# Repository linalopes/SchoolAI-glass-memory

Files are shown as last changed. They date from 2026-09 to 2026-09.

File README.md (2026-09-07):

# Glass Memory

A memory game played with the hands, on glass.

Five MDF hands sit on a transparent pane. Four of them hold a lamp. The fifth is Start. A small LED matrix waits, showing a single word. Place a hand on Start, watch the lamps light a sequence, then repeat that sequence by placing your hands on the other four. Each correct round adds one more step. A wrong direction, or a pause that lasts too long, ends the game and returns the panel to waiting.

The electronics stay visible: TRRS cables run across the glass, a custom controller board sits beside the display, and the lamps switch through a relay module. Nothing on the matrix ever names a direction. The sequence exists only as light, then as remembered gesture.

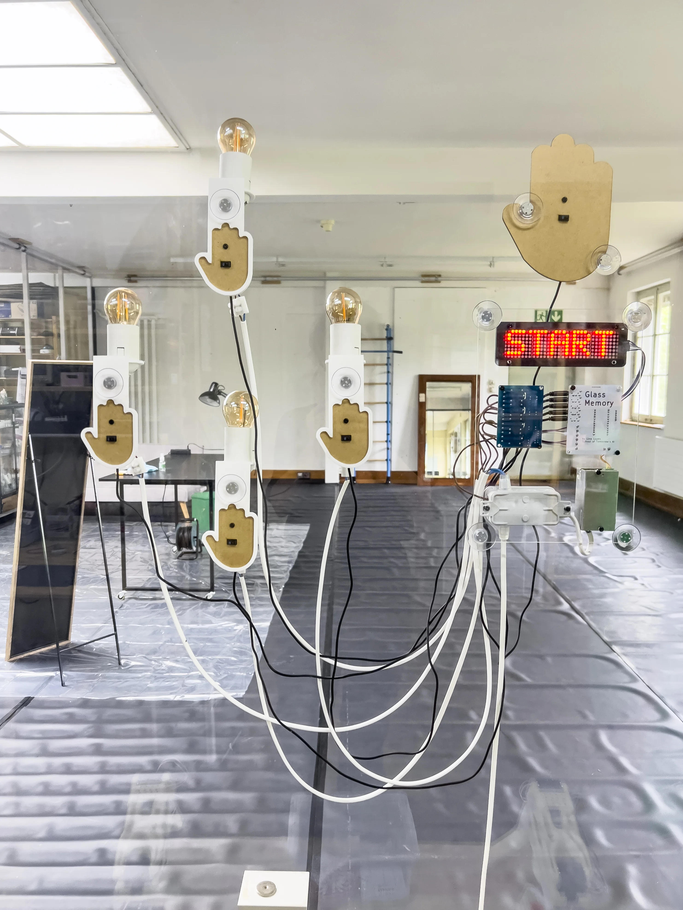
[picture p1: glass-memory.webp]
Glass Memory installation


https://github.com/user-attachments/assets/acf82029-6c34-4761-a3db-518c1ffbd78a

---

## How it works

The visitor sees a glass pane with five hand-shaped stations, a red 32×8 LED matrix, and four lamps.

1. The matrix shows **START**.
2. A hand over the Start station begins a game. Start does not light a lamp.
3. The matrix counts **3 · 2 · 1**, then shows the round length as a number.
4. The computer plays the sequence on the four direction lamps only. The display stays blank during playback and never reveals UP, DOWN, LEFT, or RIGHT as text.
5. The matrix shows **GO**. The visitor repeats the sequence on the four direction hands, one press at a time, releasing each hand before the next.
6. A complete correct round shows **OK**. The sequence grows by one random direction and the next round begins.
7. A wrong hand shows **WR**. Taking too long to press, or holding a press too long, shows **TO**. The matrix then shows the number of completed rounds and returns to **START**.

Repeated presses of the same direction count as separate events, as long as the hand is lifted in between. Only Start is accepted while idle; only the four directions are accepted during a turn.

`Start → countdown → watch lamps → GO → repeat → OK → longer sequence`

---

## System overview

```text
Five analog sensors (START, UP, DOWN, LEFT, RIGHT)
        ↓  TRRS cables + adapter boards
Arduino Pro Micro controller
        ↓
Game logic  (sequence, input events, EEPROM calibration)
   ↙                    ↘
MAX7219 matrix         4-channel relay module
(text / numbers)               ↓
                         Direction lamps
```

The controller reads five analog sensor channels, decides when a hand is present, and either plays a lamp sequence or checks the player’s reply. Calibration values live in EEPROM and are loaded at boot; the game firmware does not rewrite them.

---

## Hardware

The running firmware and the KiCad controller project both target a **SparkFun Pro Micro C** (ATmega32U4, [product 15795](https://www.sparkfun.com/products/15795)), socketed on the custom board.

The schematic title block still says “ESP32-S3 controller”. That comment is leftover. The symbol, footprint, pin map, and firmware all use the Pro Micro.

| Role | What is in this repo | Purpose |
| --- | --- | --- |
| Controller | SparkFun Pro Micro C on the [glass-memory](kicad%20files/glass-memory/) PCB | Runs calibration or game firmware |
| Sensor jacks | Five **PJ-320A** TRRS sockets (START, UP, DOWN, LEFT, RIGHT) | Detachable cable to each hand |
| Sensor adapters | Five [sensor-trrs-adapter-pj320a](kicad%20files/sensor-trrs-adapter-pj320a/) boards | PJ-320A jack to a 1×4 sensor header |
| Sensors | Five analog channels; 4-pin modules with **A0 / D0 / GND / VCC** on the adapter silkscreen | Detect a hand over each station |
| Display | External **MAX7219** 4-in-1 matrix (`FC16_HW`, 4 devices → 32×8) | Status text and numbers |
| Relays | External **4-channel relay module**, active LOW | Switch the four direction lamps |
| Power | 2-pin screw terminal **J8**, “5V Power Source” (pin 1 GND, pin 2 +5V) | 5 V rail shared with the Pro Micro `5V` pin |
| Mechanics | Laser-cut hands / board, 3D-printed hand support and matrix bezel | Physical stations on the glass |

The exact sensor part number is not named in the repository. Firmware comments treat the readings as optical (a slow “ambient optical drift” tracker). The adapter exposes both analog (**A0** / `AO`) and digital (**D0** / `DO`) pins; **only analog is used** by the firmware.

The installation photograph shows filament lamps at the four direction stations. This repository does not document lamp voltage or mains wiring. The relay stage switches those loads; any mains work must follow appropriate electrical safety practice.

### Controller pin map

Verified in both [glass-memory-game.ino](glass-memory-game/glass-memory-game.ino) and [glass-memory-calibration-eeprom.ino](glass-memory-calibration-eeprom/glass-memory-calibration-eeprom.ino), and matched on the Pro Micro footprint in the PCB.

| Function | Pin |
| --- | --- |
| START sensor | A10 |
| UP sensor | A9  |
| DOWN sensor | A8  |
| LEFT sensor | A0  |
| RIGHT sensor | A7  |
| Relay IN1 (UP) | D5  |
| Relay IN2 (DOWN)  | D4  |
| Relay IN3 (LEFT)  | D3  |
| Relay IN4 (RIGHT) | D2  |
| MAX7219 DIN | D15 |
| MAX7219 CS | D14 |
| MAX7219 CLK | D16 |

Relays are **active LOW** (`RELAY_ON = LOW`). START has no relay.

---

## Custom electronics

Two KiCad 10 projects ship with production gerbers. They are the current hardware, not a paper design only.

### Controller — [kicad files/glass-memory](kicad%20files/glass-memory/)

Silkscreen: *Glass Memory Controller 2026 - v1.0*. Outline **60 × 80 mm** with 2 mm corner radii (`Edge.Cuts` from 50.5,45 to 110.5,125), plus M3 holes.

The board is a hub:

- **U1** — socketed Pro Micro C
- **J1–J5** — PJ-320A TRRS jacks labeled START, UP, DOWN, LEFT, RIGHT
- **J6** — Phoenix MKDS 6-pin screw terminal, “RELAY 4 module”: `RELAY_IN4`, `RELAY_IN3`, `RELAY_IN2`, `RELAY_IN1`, `GND`, `+5V` (pins 1–6)
- **J7** — 5-pin header, “MAX7219 module”: `+5V`, `GND`, `DIN`, `CS`, `CLK` (pins 1–5)
- **J8** — Phoenix MKDS 2-pin screw terminal for 5 V in (pin 1 `GND`, pin 2 `+5V`). There is no on-board regulator; U1 `RAW` is unconnected.

Gerbers: [kicad files/glass-memory/production/](kicad%20files/glass-memory/production/).

### Sensor adapter — [kicad files/sensor-trrs-adapter-pj320a](kicad%20files/sensor-trrs-adapter-pj320a/)

Silkscreen: *TRRS PJ-320A 1×4 ADAPTER*. Schematic comment: *PJ-320A TRRS jack → 1×4 female header*.

One adapter sits at each hand. Board size in the gerber job is **24.6 × 15.1 mm**. The 1×4 header (J1) is:

| Pin | Net | Back silk |
| --- | ----- | --- |
| 1 | `AO`  | `A0` |
| 2 | `DO`  | `D0` |
| 3 | `GND` | `GND` |
| 4 | `3V3` | `VCC` |

Gerbers: [kicad files/sensor-trrs-adapter-pj320a/production/](kicad%20files/sensor-trrs-adapter-pj320a/production/).

---

## Sensor cabling

TRRS (PJ-320A, 3.5 mm 4-pole) is used so each hand can be a remote node: power, ground, and analog return travel in one detachable cable from the glass to the hub.

The table below follows the **PCB copper** on both boards (and the matching gerbers), using the custom [TRRS-PJ-320A](kicad%20files/glass-memory/TRRS-PJ-320A.pretty/TRRS-PJ-320A.kicad_mod) footprint labels.

| TRRS contact | Symbol pin | Controller PCB | Adapter PCB |
| --- | --- | --- | --- |
| Sleeve | S / pad 1  | `GND` | `GND` |
| Tip | T / pad 2  | not connected  | `DO` (digital out) |
| Ring 1 | R1 / pad 3 | `+5V` | net labeled `3V3` / silk `VCC` |
| Ring 2 | R2 / pad 4 | analog `*_A0`  | `AO` |

The controller uses **three** conductors. Tip is unused on the hub, so the sensor digital output is not read.

**Ambiguities to be aware of:**

1. The hub schematic *labels* next to the jacks appear to swap Sleeve and Ring 1 relative to the PCB (`+5V` on Sleeve, `GND` on Ring 1). The PCB, gerbers, and adapter all agree the other way: Sleeve = ground, Ring 1 = power. This README follows the copper.
2. The hub puts **+5 V** on Ring 1. The adapter net for that same contact is named **3V3**. Confirm the sensor module’s supply rating before applying power. TODO: document the intended sensor supply and module part number.

---

## Sensors

Five analog inputs, mapped as START / UP / DOWN / LEFT / RIGHT.

Each reading is an average of four ADC samples (first conversion after a channel change is discarded), then exponentially smoothed (`75%` previous + `25%` new). Presence is not a raw threshold. After calibration, a score of `0%` is the resting baseline and `100%` is the stored hand sample:

- press when score ≥ **50%** and that sensor beats the next by **10%**
- release when score < **30%**
- a press must stay stable **80 ms**; after release, the allowed sensors must stay neutral **120 ms** before the next press can arm

During a player turn the RAM baseline slowly follows ambient optical drift (every 100 ms, only while a sensor is well below the press threshold). EEPROM is not updated. The useful span is not allowed to collapse below a live delta of 20.

The game firmware latches one accepted sensor until *that same* sensor releases, so LEFT → LEFT is two events if the hand lifts in between.

---

## Calibration

Firmware: [glass-memory-calibration-eeprom/glass-memory-calibration-eeprom.ino](glass-memory-calibration-eeprom/glass-memory-calibration-eeprom.ino)

Optical rest levels shift with light and mounting. Calibration measures a clear-pane baseline and a hand sample per station, stores both in EEPROM, and is a **separate sketch** from the game.

Upload this sketch to the Pro Micro (Arduino IDE, board: SparkFun Pro Micro / ATmega32U4). Serial is 115200 baud. Calibration still runs if Serial is not open.

### Automatic flow

The matrix and Serial walk through the same sequence:

```text
CAL
CLEAR   → keep the complete sensor area clear → 3 · 2 · 1 → baseline
START   → prepare a hand over START → 3 · 2 · 1 → hand sample
UP      → same
DOWN
LEFT
RIGHT
DONE    → values written to EEPROM
TEST    → live sensor + relay check
```

Each measurement averages **120** analog samples with **4 ms** between samples. For every sensor the sketch stores:

- `baseline` — mean of the clear-pane capture
- `hand` — mean of that station’s hand capture
- `delta` — `hand − baseline`

Min/max during each capture are printed for noise diagnosis. The EEPROM record is:

```text
magic 0x474D ("GM") · version 1 · baseline[5] · hand[5] · checksum
```

The write is read back immediately (`EEPROM SAVE: OK` or `ERROR`). Values persist across power cycles. Resetting the board runs the whole calibration again.

### Live test

After SAVE, the sketch stays in TEST. An accepted sensor lights its relay (except START) and draws a marker on the matrix (center / top / bottom / left / right edge). Serial prints all five `filtered/score%` values twice a second, tagged `[ACTIVE]`, `[CAND]`, or `[--]`.

Send `P` on Serial to reprint the calibration table.

Then upload the game sketch. Do not recalibrate unless the mounting or lighting changed.

---

## Firmware

Current game firmware: [glass-memory-game/glass-memory-game.ino](glass-memory-game/glass-memory-game.ino) (**Game V4**).

It is not the calibration sketch. If EEPROM magic, version, checksum, or any sensor delta is invalid (`|delta| < 2`), the matrix shows **CAL** and the board waits there.

V4 responsibilities:

- load calibration; never write EEPROM
- continuous analog filter; slow RAM baseline tracking
- PRESS → LATCH → RELEASE → NEUTRAL → ARMED input machine
- idle wait on START only
- random direction sequence (UP/DOWN/LEFT/RIGHT), length 1…32
- lamp-only playback (`700 ms` on, `250 ms` gap)
- per-press timeout `10 s`, release timeout `5 s`
- player lamp feedback while the accepted hand is present (`PLAYER_LAMP_FEEDBACK`; set to `0` only for A/B diagnostics — computer playback always uses the lamps)
- serial debug at 115200 when `DEBUG_SERIAL` is 1

---

## Display

A four-module MAX7219 chain (`MD_MAX72XX::FC16_HW`, intensity 3). Firmware maps pixels with **X reversed** and **Y normal** (`physicalCol = 31 − logicalCol`) so the physical panel matches the intended left-to-right text.

| When | Matrix shows |
| --- | --- |
| Idle | `START` |
| Missing calibration | `CAL` (then halt) |
| New game | `3` `2` `1` |
| Before playback | round length as a number |
| Sequence playback | blank |
| Player turn | `GO` |
| Round correct | `OK` |
| Wrong hand | `WR`, then the score |
| Timeout | `TO`, then the score |

The 3D-printed [MAX7219 bezel](3D%20print%20files/glass_memory_max7219_beze.scad) is a rear-entry frame for a 32×8 assembly (~131 mm wide including inter-module gaps).

---

## Relays and lights

Four channels, active LOW, mapped as IN1–IN4 above. During computer playback each step turns on exactly one lamp. During the player turn the matching lamp stays on while that hand remains present (if player feedback is enabled). START never drives a relay. All relays are forced off between steps, on error, and in idle.

---

## Building the system

1. Fabricate the controller and one adapter per sensor (gerbers are under each project’s `production/` folder).
2. Seat the Pro Micro in the U1 socket.
3. Wire the MAX7219 module to J7 and the 4-channel relay module to J6.
4. At each hand, plug the 4-pin sensor into the adapter header and a TRRS cable from the adapter jack to the matching hub jack.
5. Supply 5 V on J8. Confirm sensor supply (see cabling note on +5 V vs `3V3`).
6. Upload **calibration**, clear the pane, then present a hand at each named station.
7. In TEST, confirm each direction lights the intended lamp and that Serial scores separate cleanly.
8. Upload **game** firmware. If the matrix shows `CAL`, calibration is missing or invalid — go back to step 6.
9. From idle, start a game and walk a short sequence before hanging the piece.

Laser-cut hands and board: [laser cut files](laser%20cut%20files/) (72 dpi SVG, plus `board.af`). 3D-printed hand support and matrix bezel: [3D print files](3D%20print%20files/). The hand OpenSCAD file is generated from the 72 dpi SVG contour (hand size ~60 × 80 mm, 3 mm MDF).

---

## Repository structure

```text
.
├── README.md
├── glass-memory.webp                          installation photograph
├── glass-memory.mp4                           installation video
├── glass-memory-game/                         game firmware V4
│   └── glass-memory-game.ino
├── glass-memory-calibration-eeprom/           EEPROM calibration + live TEST
│   └── glass-memory-calibration-eeprom.ino
├── kicad files/
│   ├── glass-memory/                          controller PCB + gerbers
│   └── sensor-trrs-adapter-pj320a/            per-sensor TRRS adapter + gerbers
├── laser cut files/                           hands, start hand, board (SVG / Affinity)
└── 3D print files/                            hand support + MAX7219 bezel
```

KiCad local history and zip backups exist under the hardware folders; they are snapshots, not the working design.

---

## Troubleshooting

Drawn from the diagnostic paths that actually exist in firmware.

| Symptom | What the firmware is telling you |
| --- | --- |
| Matrix stuck on `CAL` | EEPROM magic/version/checksum failed, or a stored delta is ~0. Run calibration and confirm `EEPROM SAVE: OK`. |
| Start does nothing, directions work (or the reverse) | Wrong TRRS jack, or the allowed-sensor mask: idle listens only to START; play listens only to the four directions. |
| One press counted twice, or LEFT cannot follow LEFT  | The hand never returned below the 30% release score for 120 ms. Check Serial scores in the calibration TEST. |
| Wrong lamp or two lamps | Winner margin is 10%. If two sensors both cross 50%, no winner is taken. Recalibrate with only one hand in place. |
| Resting scores creep up after a while | Expected: game tracks ambient drift in RAM only. If a real touch no longer reaches ~100%, recalibrate. |
| Display text mirrored | Firmware already reverses X for this panel. If it looks wrong, the module order or `FC16_HW` wiring does not match this build. |
| Relays on when they should be off | Modules are active LOW. Confirm the board is not treating IN as active HIGH. |
| `TO` during play | 10 s to make the next press, or 5 s to release. |
| Calibration deltas tiny | Baseline and hand samples were too similar. Repeat CLEAR with the pane empty, then place the hand fully over that station. |

Serial (both sketches, 115200) prints per-sensor scores when debug is on. Calibration TEST is the right place to watch `base` / `hand` / `delta` / `noise`.

---

## Software requirements

- Arduino IDE (or any environment that can flash a Pro Micro / ATmega32U4)
- Libraries referenced by `#include`: **MD_MAX72xx**, **SPI**, **EEPROM** (SPI and EEPROM are Arduino core libraries). No versions are pinned in this repo.
- **KiCad 10** (schematic `generator_version "10.0"`)
- **OpenSCAD**, if regenerating the 3D parts

---

## Glass Memory web app

This repository does not contain a web app, simulator, or networked companion. The installation runs entirely on the Pro Micro.

TODO: link a companion app here if it lives in another repo.

---

## About the project

Glass Memory is an embodied memory game: instructions arrive as lamps on glass, and the reply is a sequence of hands. The matrix is deliberately mute about direction. What you remember is a path of gestures, not a string of arrows.

The work sits in physical computing — analog optical sensing, a visible cable plant, calibration as a ritual of settling the pane to a room — rather than a hidden black-box kiosk.

PCB silkscreen: *heavily inspired by Nathan Rabinovitch*. No exhibition history is recorded in this repository.

---

## Credits

- **Lina Lopes** — School of Tomorrow's AI (controller and adapter silkscreen, 2026 v1.0)
- Inspired by **Nathan Rabinovitch**

TODO: license. No `LICENSE` file is present in this repository.

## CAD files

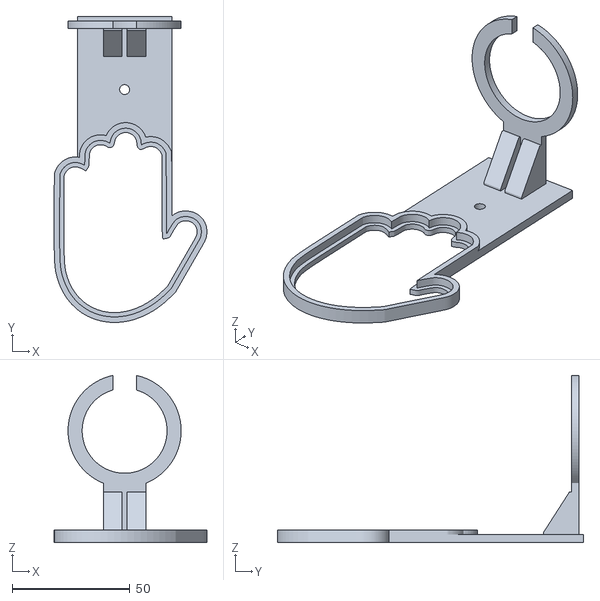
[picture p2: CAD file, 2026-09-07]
3D print files/glass_memory_hand_3Dprint.stl
64.8 x 129.8 x 70.9

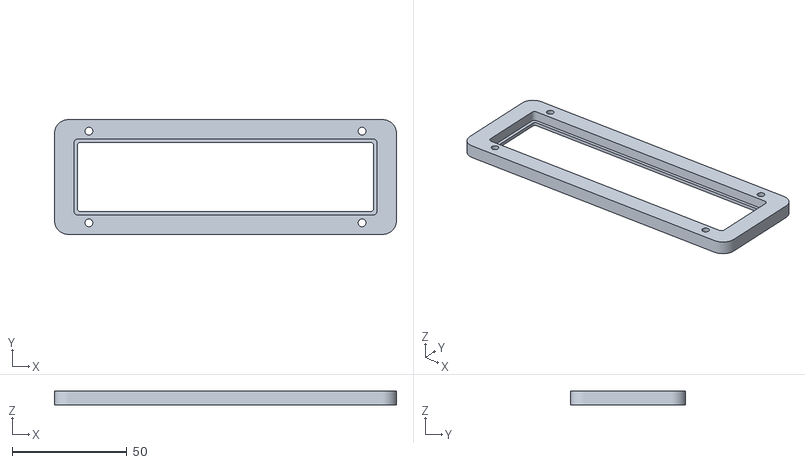
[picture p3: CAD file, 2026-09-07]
3D print files/glass_memory_max7219_bezel.stl
149.0 x 50.0 x 6.00

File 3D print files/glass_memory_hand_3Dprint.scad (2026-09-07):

// Glass Memory — hand sensor support v1
// Generated from the supplied 72 DPI SVG hand contour.
// Hand contour physical size: 59.989 x 80.002 mm
// All dimensions in mm.

$fn = 96;

// ---------- Main parameters ----------
hand_width = 59.9887;
hand_height = 80.0021;

mdf_thickness = 3.0;
mdf_clearance = 0.05  ;       // per side around MDF contour
front_bezel_thickness = 2.0;
channel_depth = 3.40;
outer_frame = 2.40;         // outside the MDF contour
front_overlap = 1.80;       // bezel overlaps MDF edge

tower_width = 40;
tower_height = 45;
tower_thickness = 3.4;
tower_overlap_into_hand = 0;
tower_bottom_y = hand_height + outer_frame;
tower_top_y = tower_bottom_y + tower_height;
// Negative = toward pinky (left in rear view). Right edge of the 40 mm tower
// aligns with the thumb-side outer hand contour (~17.5 mm after mirror + frame).
tower_x_offset = -2.5;

suction_hole_d = 4.2;
suction_hole_y = hand_height + 14;

shelf_y = tower_top_y - 5;   // shelf is as high as possible, 5 mm below top
shelf_thickness = 3.0;
rail_width = 18.0;

socket_inner_d = 36;
socket_radial_wall = 6.0;
socket_outer_d = socket_inner_d + 2*socket_radial_wall;
socket_gap = 10.0;          // lateral opening of the C-ring
socket_near_edge_offset = 20.0; // nearest edge of socket ring from rear face
socket_center_z = tower_thickness + socket_near_edge_offset + socket_outer_d/2;

// ---------- Exact hand contour ----------
hand_points = [
    [24.8773, 9.0321],
    [25.4107, 9.8499],
    [26.3283, 11.2570],
    [27.5462, 13.6811],
    [28.5143, 16.2909],
    [28.9072, 17.6181],
    [29.0130, 18.0419],
    [29.2271, 18.8989],
    [29.4792, 20.2679],
    [29.6721, 21.8559],
    [29.8142, 23.7969],
    [29.9092, 26.2229],
    [29.9094, 26.2340],
    [29.9674, 29.2669],
    [29.9944, 33.0610],
    [29.9944, 37.7370],
    [29.9835, 42.6180],
    [29.9835, 43.4290],
    [29.9354, 59.0021],
    [29.9354, 60.2790],
    [29.5623, 61.1971],
    [29.3385, 61.6831],
    [29.0704, 62.1570],
    [28.7614, 62.6131],
    [28.4164, 63.0481],
    [28.3703, 63.0981],
    [28.0404, 63.4561],
    [27.6374, 63.8331],
    [27.2125, 64.1750],
    [26.7696, 64.4771],
    [26.3135, 64.7330],
    [25.8494, 64.9409],
    [25.2205, 65.1579],
    [24.6064, 65.3129],
    [24.0015, 65.4050],
    [23.7285, 65.4180],
    [23.3986, 65.4341],
    [22.7916, 65.3989],
    [22.1764, 65.3000],
    [21.5436, 65.1349],
    [20.8895, 64.9049],
    [20.2064, 64.6070],
    [19.6325, 64.3152],
    [19.4904, 64.2429],
    [19.4724, 64.2689],
    [19.4534, 64.3639],
    [19.4335, 64.5210],
    [19.4126, 64.7351],
    [19.3925, 65.0010],
    [19.3724, 65.3119],
    [19.3536, 65.6640],
    [19.3385, 65.9934],
    [19.3385, 66.0501],
    [19.3224, 66.4649],
    [19.3084, 66.9041],
    [19.2986, 67.1941],
    [19.2785, 67.7410],
    [19.2414, 68.4530],
    [19.1904, 69.0600],
    [19.1665, 69.2420],
    [19.1224, 69.5809],
    [19.0324, 70.0349],
    [18.9144, 70.4429],
    [18.7654, 70.8221],
    [18.5805, 71.1930],
    [18.5226, 71.2901],
    [18.3540, 71.5740],
    [18.0820, 71.9849],
    [17.8510, 72.3011],
    [17.6002, 72.6030],
    [17.3301, 72.8911],
    [17.0422, 73.1631],
    [16.7382, 73.4171],
    [16.4199, 73.6550],
    [16.0879, 73.8719],
    [15.7460, 74.0701],
    [15.5391, 74.1722],
    [15.3920, 74.2450],
    [15.0301, 74.3990],
    [14.4591, 74.5770],
    [13.8352, 74.6972],
    [13.1769, 74.7580],
    [12.5030, 74.7652],
    [11.8299, 74.7181],
    [11.4431, 74.6599],
    [11.1780, 74.6199],
    [10.5639, 74.4720],
    [10.0059, 74.2770],
    [9.5230, 74.0370],
    [9.3950, 73.9442],
    [9.1320, 73.7531],
    [9.0290, 73.6640],
    [8.9420, 73.6021],
    [8.9010, 73.5851],
    [8.8690, 73.5719],
    [8.8081, 73.5769],
    [8.7549, 73.6211],
    [8.7070, 73.7071],
    [8.6610, 73.8399],
    [8.6139, 74.0230],
    [8.5639, 74.2611],
    [8.5081, 74.5569],
    [8.4679, 74.7194],
    [8.3065, 75.3711],
    [8.2964, 75.3861],
    [8.0141, 76.1349],
    [7.6421, 76.8451],
    [7.3431, 77.2769],
    [7.1920, 77.4951],
    [6.6679, 78.0820],
    [6.0750, 78.6011],
    [5.4180, 79.0469],
    [4.6999, 79.4150],
    [3.9271, 79.7031],
    [3.2471, 79.8682],
    [3.1040, 79.9031],
    [2.0070, 80.0021],
    [0.9299, 79.9031],
    [-0.1089, 79.6240],
    [-0.4221, 79.4822],
    [-0.8489, 79.2885],
    [-1.0860, 79.1811],
    [-1.9821, 78.5910],
    [-2.7740, 77.8711],
    [-3.4410, 77.0350],
    [-3.9609, 76.1032],
    [-4.2110, 75.3861],
    [-4.3139, 75.0901],
    [-4.4779, 74.0130],
    [-4.4901, 73.8291],
    [-4.5020, 73.6542],
    [-4.5171, 73.4909],
    [-4.5319, 73.3420],
    [-4.5324, 73.3380],
    [-4.5491, 73.2091],
    [-4.5650, 73.0962],
    [-4.5819, 73.0030],
    [-4.5981, 72.9340],
    [-4.6139, 72.8911],
    [-4.6290, 72.8750],
    [-4.6499, 72.8789],
    [-4.6830, 72.8911],
    [-4.7269, 72.9110],
    [-4.7801, 72.9361],
    [-4.8431, 72.9671],
    [-4.9121, 73.0041],
    [-4.9449, 73.0221],
    [-4.9870, 73.0451],
    [-5.0669, 73.0901],
    [-5.1500, 73.1380],
    [-5.2349, 73.1890],
    [-5.2669, 73.2054],
    [-5.7773, 73.4711],
    [-6.3663, 73.6970],
    [-6.9912, 73.8669],
    [-7.6421, 73.9820],
    [-8.3062, 74.0399],
    [-8.9732, 74.0410],
    [-9.0412, 74.0349],
    [-9.6312, 73.9831],
    [-10.2691, 73.8680],
    [-10.8753, 73.6941],
    [-11.4391, 73.4610],
    [-11.8183, 73.2560],
    [-12.1942, 73.0160],
    [-12.5633, 72.7440],
    [-12.9203, 72.4450],
    [-13.2621, 72.1209],
    [-13.5852, 71.7780],
    [-13.8852, 71.4190],
    [-13.9802, 71.2901],
    [-14.1575, 71.0491],
    [-14.3993, 70.6710],
    [-14.6054, 70.2889],
    [-15.0943, 69.2891],
    [-15.0943, 67.1941],
    [-15.1163, 59.0021],
    [-15.1343, 52.2301],
    [-15.1444, 49.4731],
    [-15.1565, 46.8529],
    [-15.1713, 44.4071],
    [-15.1854, 42.6180],
    [-15.1854, 42.1719],
    [-15.2044, 40.1820],
    [-15.2245, 38.5220],
    [-15.2251, 38.4741],
    [-15.2460, 37.0829],
    [-15.2589, 36.4741],
    [-15.2690, 36.0450],
    [-15.2909, 35.3949],
    [-15.3140, 35.1711],
    [-15.3391, 35.1771],
    [-15.3671, 35.1930],
    [-15.3989, 35.2190],
    [-15.4330, 35.2541],
    [-15.4431, 35.2660],
    [-15.4679, 35.2970],
    [-15.5050, 35.3470],
    [-15.5410, 35.4031],
    [-15.5769, 35.4640],
    [-15.6000, 35.5063],
    [-15.6129, 35.5301],
    [-15.6460, 35.5992],
    [-15.8640, 36.0392],
    [-16.1011, 36.4741],
    [-16.1551, 36.5731],
    [-16.5019, 37.1710],
    [-16.8869, 37.8060],
    [-17.2261, 38.3455],
    [-17.2909, 38.4490],
    [-17.3391, 38.5220],
    [-17.6973, 39.0721],
    [-18.0844, 39.6460],
    [-18.4384, 40.1431],
    [-18.7374, 40.5350],
    [-18.7684, 40.5701],
    [-18.9655, 40.7921],
    [-19.3033, 41.1009],
    [-19.6484, 41.3761],
    [-20.0045, 41.6190],
    [-20.3715, 41.8301],
    [-20.7514, 42.0100],
    [-21.1475, 42.1611],
    [-21.3224, 42.2124],
    [-21.5605, 42.2820],
    [-21.9934, 42.3751],
    [-22.4463, 42.4410],
    [-22.9234, 42.4791],
    [-23.5385, 42.4910],
    [-24.1354, 42.4601],
    [-24.7135, 42.3881],
    [-25.2684, 42.2751],
    [-25.4184, 42.2317],
    [-25.8015, 42.1211],
    [-26.3095, 41.9272],
    [-26.7913, 41.6930],
    [-27.2445, 41.4210],
    [-27.6695, 41.1102],
    [-28.0624, 40.7612],
    [-28.4764, 40.3302],
    [-28.8365, 39.8931],
    [-29.1445, 39.4441],
    [-29.4025, 38.9811],
    [-29.6025, 38.5220],
    [-29.6123, 38.4990],
    [-29.7753, 37.9950],
    [-29.8914, 37.4642],
    [-29.9645, 36.9020],
    [-29.9944, 36.3061],
    [-29.9835, 35.6711],
    [-29.9573, 35.1951],
    [-29.9174, 34.7789],
    [-29.8515, 34.4260],
    [-29.8414, 34.3831],
    [-29.7134, 33.9590],
    [-29.5115, 33.4661],
    [-29.2154, 32.8591],
    [-28.8053, 32.0940],
    [-28.2613, 31.1280],
    [-27.8031, 30.3300],
    [-27.5655, 29.9159],
    [-26.6955, 28.4149],
    [-26.2875, 27.7119],
    [-26.0978, 27.3841],
    [-25.8094, 26.8851],
    [-25.4324, 26.2340],
    [-25.2705, 25.9540],
    [-24.6855, 24.9409],
    [-24.0645, 23.8670],
    [-23.4213, 22.7531],
    [-23.1972, 22.3639],
    [-22.7683, 21.6202],
    [-22.1164, 20.4891],
    [-21.4785, 19.3831],
    [-20.8673, 18.3211],
    [-20.7067, 18.0419],
    [-17.2655, 12.0650],
    [-17.2245, 12.0240],
    [-15.4253, 10.2259],
    [-15.0205, 9.8499],
    [-13.1584, 8.1209],
    [-10.8084, 6.2460],
    [-8.3864, 4.6069],
    [-5.9054, 3.2089],
    [-3.3783, 2.0550],
    [-0.8404, 1.1610],
    [-0.8174, 1.1509],
    [1.7657, 0.5051],
    [4.3557, 0.1201],
    [6.9425, 0.0000],
    [7.3516, 0.0241],
    [9.5135, 0.1519],
    [12.1567, 0.6077],
    [14.6776, 1.3568],
    [15.5436, 1.7312],
    [15.8127, 1.8476],
    [17.0605, 2.3868],
    [19.2885, 3.6819],
    [21.3467, 5.2290],
    [23.2176, 7.0167],
    [24.8876, 9.0300]
];

module hand2d() {
    mirror([1,0,0]) polygon(points=hand_points);
}

module front_bezel_2d() {
    difference() {
        offset(r=outer_frame) hand2d();
        offset(delta=-front_overlap) hand2d();
    }
}
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

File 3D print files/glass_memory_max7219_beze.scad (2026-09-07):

/*
  Glass Memory — MAX7219 32x8 front bezel / mounting frame — v2

  Adjusted for 4-in-1 matrices with ~1 mm gap between the four 8x8 modules.
  Estimated active assembly width: 4 x 32 mm + 3 x 1 mm = 131 mm.

  Design:
  - MAX7219 enters from the rear
  - thin front retaining lip
  - rear remains open
  - rounded outer corners
  - four M3 clearance holes in the bezel
*/

$fn = 64;

// ---------- User parameters ----------
module_w = 131.0;          // 128 mm + ~3 mm total inter-module gaps
module_h = 32.0;
module_clearance = 1.0;    // total clearance: 0.5 mm per side

// 1.5 mm retaining lip around the module face
opening_w = 129.0;
opening_h = 30.0;

// Keep the same frame margins as v1, adding 3 mm to overall width
outer_w = 149.0;
outer_h = 50.0;
outer_r = 6.0;

// Depth geometry
bezel_depth = 6.0;
front_lip_thickness = 1.5;

// M3 clearance holes
screw_d = 3.4;
screw_x_inset = 15.0;
screw_y_inset = 5.0;

// ---------- Derived values ----------
pocket_w = module_w + module_clearance; // 132 mm
pocket_h = module_h + module_clearance; // 33 mm

// ---------- Helpers ----------
module rounded_rect_2d(w, h, r) {
  hull() {
    translate([ r,  r]) circle(r=r);
    translate([w-r,  r]) circle(r=r);
    translate([ r, h-r]) circle(r=r);
    translate([w-r,h-r]) circle(r=r);
  }
}

module centered_rounded_rect_prism(w, h, d, r) {
  translate([-w/2, -h/2, 0])
    linear_extrude(height=d)
      rounded_rect_2d(w, h, r);
}

module screw_hole(x, y) {
  translate([x, y, -0.5])
    cylinder(h=bezel_depth + 1.0, d=screw_d);
}

// ---------- Final model ----------
difference() {
  centered_rounded_rect_prism(outer_w, outer_h, bezel_depth, outer_r);

  // Front viewing opening
  translate([0, 0, -0.5])
    centered_rounded_rect_prism(opening_w, opening_h, bezel_depth + 1.0, 1.2);

  // Rear pocket
  translate([0, 0, front_lip_thickness])
    centered_rounded_rect_prism(
      pocket_w,
      pocket_h,
      bezel_depth - front_lip_thickness + 0.5,
      1.5
    );

  // Four M3 clearance holes
  for (sx = [-1, 1])
    for (sy = [-1, 1])
      screw_hole(
        sx * (outer_w/2 - screw_x_inset),
        sy * (outer_h/2 - screw_y_inset)
      );
}

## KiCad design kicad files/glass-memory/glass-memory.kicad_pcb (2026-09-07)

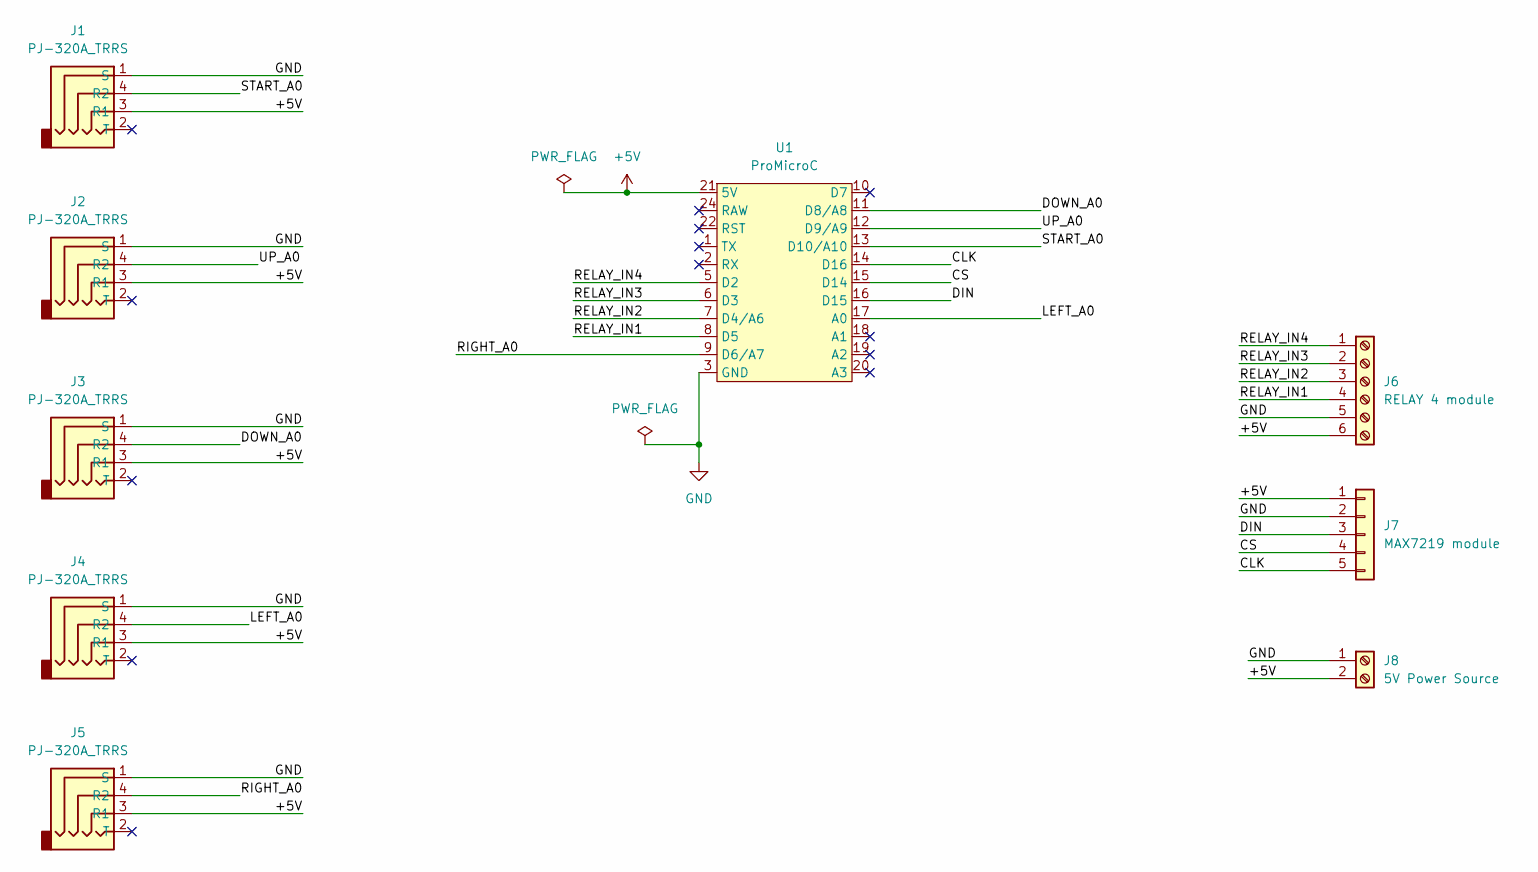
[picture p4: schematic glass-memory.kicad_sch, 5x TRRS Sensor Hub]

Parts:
J1, J2, J3, J4, J5: PJ-320A_TRRS; TRRS-PJ-320A
J6: RELAY 4 module; TerminalBlock_Phoenix_MKDS-1,5-6-5.08_1x06_P5.08mm_Horizont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
J7: MAX7219 module; PinHeader_1x05_P2.54mm_Vertical
J8: 5V Power Source; TerminalBlock_Phoenix_MKDS-1,5-2-5.08_1x02_P5.08mm_Horizont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
U1: ProMicroC; ProMicroC-socketed

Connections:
+5V: J1.3 (R1), J2.3 (R1), J3.3 (R1), J4.3 (R1), J5.3 (R1), J6.6, J7.1, J8.2, U1.21 (5V)
/CLK: J7.5, U1.14 (D16)
/CS: J7.4, U1.15 (D14)
/DIN: J7.3, U1.16 (D15)
/DOWN_A0: J3.4 (R2), U1.11 (D8/A8)
/LEFT_A0: J4.4 (R2), U1.17 (A0)
/RELAY_IN1: J6.4, U1.8 (D5)
/RELAY_IN2: J6.3, U1.7 (D4/A6)
/RELAY_IN3: J6.2, U1.6 (D3)
/RELAY_IN4: J6.1, U1.5 (D2)
/RIGHT_A0: J5.4 (R2), U1.9 (D6/A7)
/START_A0: J1.4 (R2), U1.13 (D10/A10)
/UP_A0: J2.4 (R2), U1.12 (D9/A9)
GND: J1.1 (S), J2.1 (S), J3.1 (S), J4.1 (S), J5.1 (S), J6.5, J7.2, J8.1, U1.3 (GND), U1.4 (GND), U1.23 (GND)

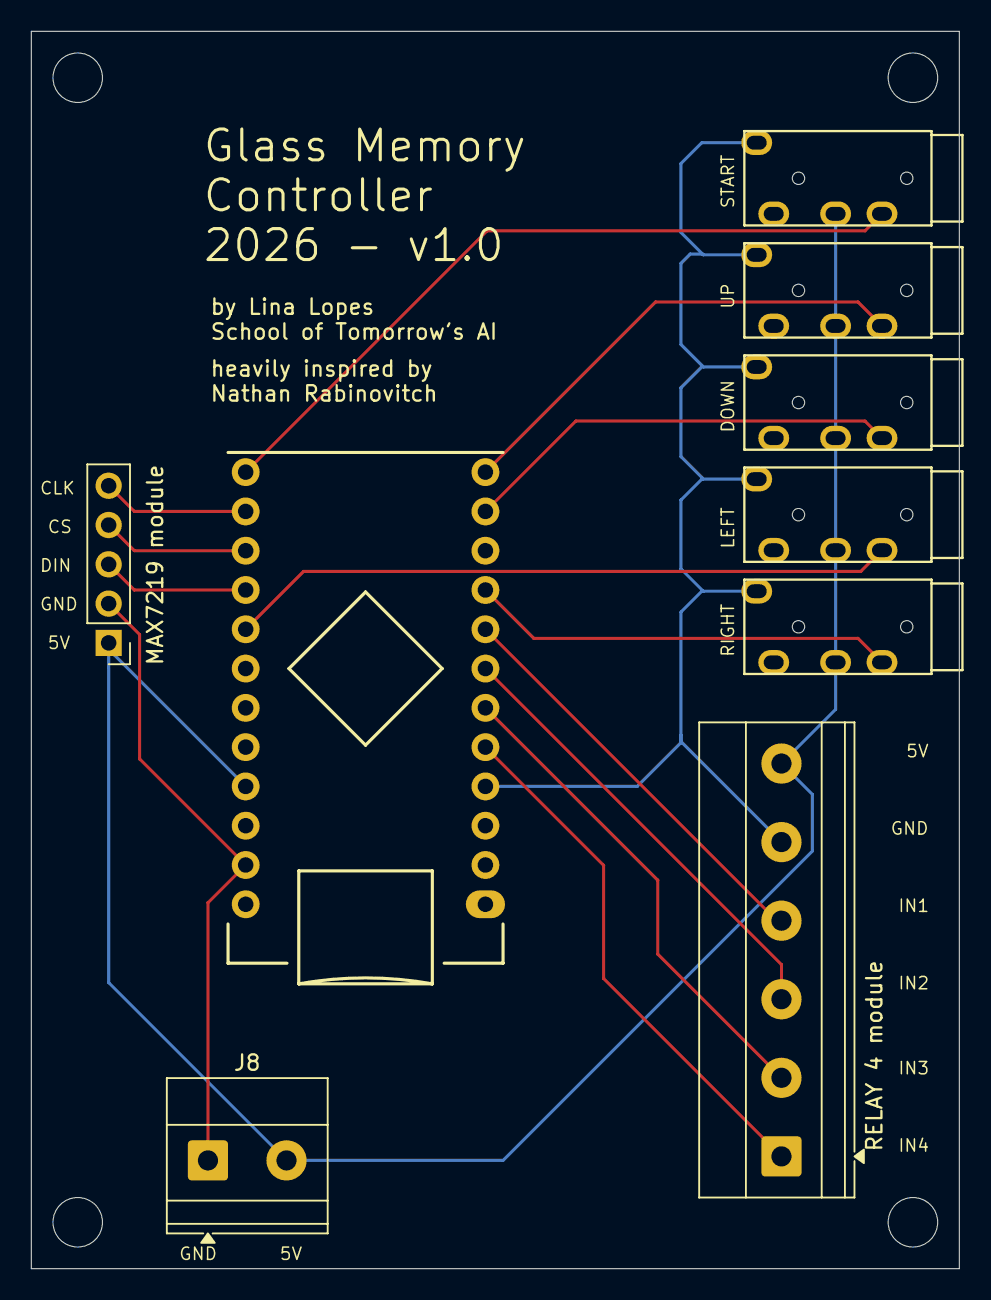
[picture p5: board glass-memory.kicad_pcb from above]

Board: 2 copper layers, 60.0 x 80.0 mm, 9 parts (0 on the bottom side), 14 nets.

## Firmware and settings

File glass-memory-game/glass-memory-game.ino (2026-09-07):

#include <MD_MAX72xx.h>
#include <SPI.h>
#include <EEPROM.h>

// ============================================================
// GLASS MEMORY - GAME V4
// Board: Arduino Pro Micro / ATmega32U4
//
// V4 is rebuilt around the validated PRESS -> LATCH ->
// RELEASE -> NEUTRAL -> ARMED input detector.
//
// Main changes from V1/V2/V3:
// - One sensor press is latched until THAT SAME sensor releases.
// - Repeated directions such as LEFT -> LEFT are independent events.
// - START only participates while idle.
// - Only UP/DOWN/LEFT/RIGHT participate during the player turn.
// - The analog filter stays continuous inside a player round.
// - The resting baseline slowly follows ambient optical drift in RAM.
// - EEPROM calibration is never rewritten by the game.
// - Player input timeout is per expected press.
// - Relay/lamp feedback stays on while the accepted hand is present.
//
// Display:
// - X axis reversed
// - Y axis normal
// - Display never reveals a direction.
//
// Relays:
// - ACTIVE LOW
// - IN1 = UP    -> D5
// - IN2 = DOWN  -> D4
// - IN3 = LEFT  -> D3
// - IN4 = RIGHT -> D2
// ============================================================


// ------------------------------------------------------------
// DEBUG
// ------------------------------------------------------------

#define DEBUG_SERIAL 1

#if DEBUG_SERIAL
  #define DBG_BEGIN(baud) Serial.begin(baud)
  #define DBG_PRINT(x) Serial.print(x)
  #define DBG_PRINTLN(x) Serial.println(x)
#else
  #define DBG_BEGIN(baud)
  #define DBG_PRINT(x)
  #define DBG_PRINTLN(x)
#endif


// ------------------------------------------------------------
// PLAYER LAMP FEEDBACK
//
// Set to 0 only for A/B diagnostics.
// Computer sequence playback always uses the lamps.
// ------------------------------------------------------------

#define PLAYER_LAMP_FEEDBACK 1


// ------------------------------------------------------------
// MAX7219
// ------------------------------------------------------------

#define HARDWARE_TYPE MD_MAX72XX::FC16_HW
#define MAX_DEVICES 4

#define DATA_PIN 15
#define CS_PIN   14
#define CLK_PIN  16

MD_MAX72XX matrix(
  HARDWARE_TYPE,
  DATA_PIN,
  CLK_PIN,
  CS_PIN,
  MAX_DEVICES
);


// ------------------------------------------------------------
// RELAYS
// ------------------------------------------------------------

const uint8_t RELAY_UP_PIN    = 5;
const uint8_t RELAY_DOWN_PIN  = 4;
const uint8_t RELAY_LEFT_PIN  = 3;
const uint8_t RELAY_RIGHT_PIN = 2;

const uint8_t RELAY_ON  = LOW;
const uint8_t RELAY_OFF = HIGH;


// ------------------------------------------------------------
// ANALOG SENSOR PINOUT
// ------------------------------------------------------------

const uint8_t START_PIN = A10;
const uint8_t UP_PIN    = A9;
const uint8_t DOWN_PIN  = A8;
const uint8_t LEFT_PIN  = A0;
const uint8_t RIGHT_PIN = A7;


enum SensorId
{
  START_ID = 0,
  UP_ID,
  DOWN_ID,
  LEFT_ID,
  RIGHT_ID,
  SENSOR_COUNT
};


const uint8_t sensorPins[SENSOR_COUNT] =
{
  START_PIN,
  UP_PIN,
  DOWN_PIN,
  LEFT_PIN,
  RIGHT_PIN
};


const char* sensorNames[SENSOR_COUNT] =
{
  "START",
  "UP",
  "DOWN",
  "LEFT",
  "RIGHT"
};


// Only sensors relevant to the current game state may compete.
const uint8_t START_SENSOR_MASK =
  (1 << START_ID);

const uint8_t DIRECTION_SENSOR_MASK =
  (1 << UP_ID) |
  (1 << DOWN_ID) |
  (1 << LEFT_ID) |
  (1 << RIGHT_ID);


// ------------------------------------------------------------
// EEPROM CALIBRATION FORMAT
//
// MUST remain identical to glass-memory-calibration-eeprom.ino
// ------------------------------------------------------------

const uint16_t EEPROM_MAGIC = 0x474D;  // "GM"
const uint8_t EEPROM_VERSION = 1;
const int EEPROM_ADDRESS = 0;

struct StoredCalibration
{
  uint16_t magic;
  uint8_t version;
  int16_t baseline[SENSOR_COUNT];
  int16_t hand[SENSOR_COUNT];
  uint16_t checksum;
};


// ------------------------------------------------------------
// ACTIVE CALIBRATION
//
// baseline[] is the live RAM baseline.
// EEPROM is never modified by the game.
// ------------------------------------------------------------

int16_t baseline[SENSOR_COUNT];
int16_t handValue[SENSOR_COUNT];
int16_t deltaValue[SENSOR_COUNT];

// Q8 fixed-point baseline for slow ambient tracking.
long baselineQ8[SENSOR_COUNT];


// ------------------------------------------------------------
// LIVE SENSOR DATA
// ------------------------------------------------------------

int16_t rawValue[SENSOR_COUNT];
int16_t filteredValue[SENSOR_COUNT];
int16_t scorePercent[SENSOR_COUNT];

bool filtersInitialized = false;


// ------------------------------------------------------------
// SENSOR SETTINGS
// ------------------------------------------------------------

const uint8_t ADC_AVERAGE_SAMPLES = 4;

// filtered = 75% previous + 25% new
const uint8_t FILTER_OLD_WEIGHT = 3;
const uint8_t FILTER_TOTAL_WEIGHT = 4;

// 0% = current resting baseline
// 100% = calibrated hand position
const int16_t TRIGGER_SCORE = 50;
const int16_t RELEASE_SCORE = 30;

const int16_t WINNER_MARGIN = 10;

const unsigned long PRESS_STABLE_MS   = 80;
const unsigned long RELEASE_STABLE_MS = 80;
const unsigned long REARM_NEUTRAL_MS  = 120;


// ------------------------------------------------------------
// SLOW AMBIENT BASELINE TRACKING
//
// The last tests showed resting values drifting to roughly
// 20-35% after calibration while real touches were ~95-102%.
//
// Tracking is deliberately slow and only occurs while a sensor
// is well below the press threshold. It changes RAM only.
// ------------------------------------------------------------

const int16_t BASELINE_TRACK_MAX_SCORE = 45;

const unsigned long BASELINE_TRACK_INTERVAL_MS = 100;

// Each tracking step moves 1/64 of the remaining error.
// At 100 ms per step this is intentionally slow.
const uint8_t BASELINE_TRACK_DIVISOR = 64;

// Never allow baseline tracking to collapse the useful span.
const int16_t MIN_LIVE_DELTA = 20;

unsigned long lastBaselineTrack = 0;


// ------------------------------------------------------------
// DISCRETE INPUT EVENT STATE
//
// This is the validated event machine.
// ------------------------------------------------------------

int8_t latchedSensor = -1;

int8_t candidateSensor = -1;
unsigned long candidateSince = 0;

unsigned long releaseSince = 0;
unsigned long neutralSince = 0;

bool eventArmed = false;

unsigned long inputEventCounter = 0;


// ------------------------------------------------------------
// GAME SETTINGS
// ------------------------------------------------------------

const uint8_t MAX_SEQUENCE_LENGTH = 32;

uint8_t sequence[MAX_SEQUENCE_LENGTH];
uint8_t sequenceLength = 0;
uint8_t completedRounds = 0;

const unsigned long START_COUNTDOWN_MS = 500;
const unsigned long LEVEL_DISPLAY_MS   = 600;

const unsigned long SEQUENCE_ON_MS  = 700;
const unsigned long SEQUENCE_GAP_MS = 250;

const unsigned long GO_DISPLAY_MS = 450;

// Time allowed to START a requested player press.
const unsigned long INPUT_TIMEOUT_MS = 10000;

// Once a press has been accepted, allow time for release.
const unsigned long RELEASE_TIMEOUT_MS = 5000;

const unsigned long OK_DISPLAY_MS    = 650;
const unsigned long NO_DISPLAY_MS    = 900;
const unsigned long SCORE_DISPLAY_MS = 1500;


// ------------------------------------------------------------
// 5x7 FONT
// ------------------------------------------------------------

const uint8_t FONT_AZ[26][7] PROGMEM =
{
  {0x0E,0x11,0x11,0x1F,0x11,0x11,0x11}, // A
  {0x1E,0x11,0x11,0x1E,0x11,0x11,0x1E}, // B
  {0x0E,0x11,0x10,0x10,0x10,0x11,0x0E}, // C
  {0x1E,0x11,0x11,0x11,0x11,0x11,0x1E}, // D
  {0x1F,0x10,0x10,0x1E,0x10,0x10,0x1F}, // E
  {0x1F,0x10,0x10,0x1E,0x10,0x10,0x10}, // F
  {0x0E,0x11,0x10,0x17,0x11,0x11,0x0F}, // G
  {0x11,0x11,0x11,0x1F,0x11,0x11,0x11}, // H
  {0x0E,0x04,0x04,0x04,0x04,0x04,0x0E}, // I
  {0x07,0x02,0x02,0x02,0x02,0x12,0x0C}, // J
  {0x11,0x12,0x14,0x18,0x14,0x12,0x11}, // K
  {0x10,0x10,0x10,0x10,0x10,0x10,0x1F}, // L
  {0x11,0x1B,0x15,0x15,0x11,0x11,0x11}, // M
  {0x11,0x19,0x15,0x13,0x11,0x11,0x11}, // N
  {0x0E,0x11,0x11,0x11,0x11,0x11,0x0E}, // O
  {0x1E,0x11,0x11,0x1E,0x10,0x10,0x10}, // P
  {0x0E,0x11,0x11,0x11,0x15,0x12,0x0D}, // Q
  {0x1E,0x11,0x11,0x1E,0x14,0x12,0x11}, // R
  {0x0F,0x10,0x10,0x0E,0x01,0x01,0x1E}, // S
  {0x1F,0x04,0x04,0x04,0x04,0x04,0x04}, // T
  {0x11,0x11,0x11,0x11,0x11,0x11,0x0E}, // U
  {0x11,0x11,0x11,0x11,0x11,0x0A,0x04}, // V
  {0x11,0x11,0x11,0x15,0x15,0x15,0x0A}, // W
  {0x11,0x11,0x0A,0x04,0x0A,0x11,0x11}, // X
  {0x11,0x11,0x0A,0x04,0x04,0x04,0x04}, // Y
  {0x1F,0x01,0x02,0x04,0x08,0x10,0x1F}  // Z
};


const uint8_t FONT_DIGITS[10][7] PROGMEM =
{
  {0x0E,0x11,0x13,0x15,0x19,0x11,0x0E}, // 0
  {0x04,0x0C,0x04,0x04,0x04,0x04,0x0E}, // 1
  {0x0E,0x11,0x01,0x02,0x04,0x08,0x1F}, // 2
  {0x1E,0x01,0x01,0x0E,0x01,0x01,0x1E}, // 3
  {0x02,0x06,0x0A,0x12,0x1F,0x02,0x02}, // 4
  {0x1F,0x10,0x10,0x1E,0x01,0x01,0x1E}, // 5
  {0x0E,0x10,0x10,0x1E,0x11,0x11,0x0E}, // 6
  {0x1F,0x01,0x02,0x04,0x08,0x08,0x08}, // 7
  {0x0E,0x11,0x11,0x0E,0x11,0x11,0x0E}, // 8
  {0x0E,0x11,0x11,0x0F,0x01,0x01,0x0E}  // 9
};


// ============================================================
// RELAY HELPERS
// ============================================================

void allRelaysOff()
{
  digitalWrite(RELAY_UP_PIN, RELAY_OFF);
  digitalWrite(RELAY_DOWN_PIN, RELAY_OFF);
  digitalWrite(RELAY_LEFT_PIN, RELAY_OFF);
  digitalWrite(RELAY_RIGHT_PIN, RELAY_OFF);
}


void setDirectionRelay(int8_t direction)
{
  allRelaysOff();

  switch (direction)
  {
    case UP_ID:
      digitalWrite(RELAY_UP_PIN, RELAY_ON);
      break;

    case DOWN_ID:
      digitalWrite(RELAY_DOWN_PIN, RELAY_ON);
      break;

    case LEFT_ID:
      digitalWrite(RELAY_LEFT_PIN, RELAY_ON);
      break;

    case RIGHT_ID:
      digitalWrite(RELAY_RIGHT_PIN, RELAY_ON);
      break;

    default:
      break;
  }
}


// ============================================================
// DISPLAY HELPERS
// ============================================================

void setPixel(uint8_t logicalRow, uint8_t logicalCol, bool state = true)
{
  uint8_t physicalRow = logicalRow;
  uint8_t physicalCol = 31 - logicalCol;

  matrix.setPoint(
    physicalRow,
    physicalCol,
    state
  );
}


void beginDisplayFrame()
{
  matrix.control(
    MD_MAX72XX::UPDATE,
    MD_MAX72XX::OFF
  );

  matrix.clear();
}


void endDisplayFrame()
{
  matrix.control(
    MD_MAX72XX::UPDATE,
    MD_MAX72XX::ON
  );
}


void clearDisplay()
{
  beginDisplayFrame();
  endDisplayFrame();
}


uint8_t getGlyphRow(char c, uint8_t row)
{
  if (c >= 'A' && c <= 'Z')
  {
    return pgm_read_byte(
      &FONT_AZ[c - 'A'][row]
    );
  }

  if (c >= '0' && c <= '9')
  {
    return pgm_read_byte(
      &FONT_DIGITS[c - '0'][row]
    );
  }

  return 0;
}


void drawCharacter(char c, int8_t x)
{
  for (uint8_t row = 0; row < 7; row++)
  {
    uint8_t bits =
      getGlyphRow(c, row);

    for (uint8_t col = 0; col < 5; col++)
    {
      if (bits & (1 << (4 - col)))
      {
        int8_t px = x + col;

        if (px >= 0 && px < 32)
        {
          setPixel(row, px);
        }
      }
    }
  }
}


uint8_t getTextWidth(const char* text)
{
  uint8_t length =
    strlen(text);

  if (length == 0)
  {
    return 0;
  }

  return (length * 6) - 1;
}


void showText(const char* text)
{
  beginDisplayFrame();

  uint8_t width =
    getTextWidth(text);

  int8_t x =
    (32 - width) / 2;

  for (
    uint8_t i = 0;
    text[i] != '\0';
    i++
  )
  {
    drawCharacter(
      text[i],
      x
    );

    x += 6;
  }

  endDisplayFrame();
}


void showNumber(uint8_t number)
{
  char buffer[4];

  itoa(
    number,
    buffer,
    10
  );

  showText(buffer);
}


void showCountdown()
{
  showText("3");
  delay(START_COUNTDOWN_MS);

  showText("2");
  delay(START_COUNTDOWN_MS);

  showText("1");
  delay(START_COUNTDOWN_MS);

  clearDisplay();
}


// ============================================================
// EEPROM CALIBRATION
// ============================================================

uint16_t calculateChecksum(const StoredCalibration& data)
{
  uint16_t sum =
    data.magic +
    data.version;

  for (uint8_t i = 0; i < SENSOR_COUNT; i++)
  {
    sum +=
      (uint16_t)data.baseline[i];

    sum +=
      (uint16_t)data.hand[i];
  }

  return sum;
}


bool loadCalibrationFromEEPROM()
{
  StoredCalibration data;

  EEPROM.get(
    EEPROM_ADDRESS,
    data
  );

  bool valid =
    data.magic == EEPROM_MAGIC &&
    data.version == EEPROM_VERSION &&
    data.checksum == calculateChecksum(data);

  if (!valid)
  {
    return false;
  }


  for (uint8_t i = 0; i < SENSOR_COUNT; i++)
  {
    baseline[i] =
      data.baseline[i];

    handValue[i] =
      data.hand[i];

    deltaValue[i] =
      handValue[i] -
      baseline[i];

    baselineQ8[i] =
      ((long)baseline[i]) << 8;


    if (
      deltaValue[i] > -2 &&
      deltaValue[i] < 2
    )
    {
      return false;
    }
  }


#if DEBUG_SERIAL
  DBG_PRINTLN(F("EEPROM calibration loaded:"));

  for (uint8_t i = 0; i < SENSOR_COUNT; i++)
  {
    DBG_PRINT(sensorNames[i]);

    DBG_PRINT(F(" base="));
    DBG_PRINT(baseline[i]);

    DBG_PRINT(F(" hand="));
    DBG_PRINT(handValue[i]);

    DBG_PRINT(F(" delta="));
    DBG_PRINTLN(deltaValue[i]);
  }

  DBG_PRINTLN("");
#endif

  return true;
}


// ============================================================
// ADC + FILTER + SCORE
// ============================================================

int readAnalogAveraged(uint8_t pin)
{
  // Discard first conversion after changing ADC channel.
  analogRead(pin);

  long total = 0;

  for (
    uint8_t i = 0;
    i < ADC_AVERAGE_SAMPLES;
    i++
  )
  {
    total +=
      analogRead(pin);
  }

  return
    total / ADC_AVERAGE_SAMPLES;
}


int16_t calculateScorePercent(
  uint8_t sensorId,
  int value
)
{
  int delta =
    deltaValue[sensorId];

  if (
    delta > -2 &&
    delta < 2
  )
  {
    return 0;
  }


  long numerator =
    (long)(
      value -
      baseline[sensorId]
    ) * 100L;

  long score =
    numerator / delta;


  if (score < -50)
  {
    score = -50;
  }

  if (score > 200)
  {
    score = 200;
  }


  return
    (int16_t)score;
}


void recalculateAllScores()
{
  for (uint8_t i = 0; i < SENSOR_COUNT; i++)
  {
    scorePercent[i] =
      calculateScorePercent(
        i,
        filteredValue[i]
      );
  }
}


// ------------------------------------------------------------
// Slow baseline tracking.
//
// IMPORTANT:
// - Only RAM baseline changes.
// - EEPROM calibration remains untouched.
// - Never track the currently latched sensor.
// - Never track a sensor close to a real press.
// ------------------------------------------------------------

void updateAdaptiveBaselines()
{
  if (
    millis() - lastBaselineTrack
    < BASELINE_TRACK_INTERVAL_MS
  )
  {
    return;
  }


  lastBaselineTrack =
    millis();


  for (uint8_t i = 0; i < SENSOR_COUNT; i++)
  {
    if (i == latchedSensor)
    {
      continue;
    }


    if (
      scorePercent[i]
      > BASELINE_TRACK_MAX_SCORE
    )
    {
      continue;
    }


    long targetQ8 =
      ((long)filteredValue[i]) << 8;

    long proposedQ8 =
      baselineQ8[i]
      +
      (
        targetQ8 -
        baselineQ8[i]
      )
      /
      BASELINE_TRACK_DIVISOR;

    int16_t proposedBaseline =
      (int16_t)(
        proposedQ8 >> 8
      );

    int16_t proposedDelta =
      handValue[i] -
      proposedBaseline;


    if (
      proposedDelta > -MIN_LIVE_DELTA &&
      proposedDelta < MIN_LIVE_DELTA
    )
    {
      continue;
    }


    baselineQ8[i] =
      proposedQ8;

    baseline[i] =
      proposedBaseline;

    deltaValue[i] =
      proposedDelta;
  }


  recalculateAllScores();
}


void readAllSensors(
  bool allowBaselineTracking
)
{
  for (uint8_t i = 0; i < SENSOR_COUNT; i++)
  {
    rawValue[i] =
      readAnalogAveraged(
        sensorPins[i]
      );


    if (!filtersInitialized)
    {
      filteredValue[i] =
        rawValue[i];
    }
    else
    {
      filteredValue[i] =
        (
          (long)filteredValue[i]
          *
          FILTER_OLD_WEIGHT
          +
          rawValue[i]
        )
        /
        FILTER_TOTAL_WEIGHT;
    }
  }


  filtersInitialized = true;

  recalculateAllScores();


  if (allowBaselineTracking)
  {
    updateAdaptiveBaselines();
  }
}


// ============================================================
// WINNER SELECTION
// ============================================================

int8_t findValidWinner(
  uint8_t allowedMask
)
{
  int8_t bestSensor = -1;

  int16_t bestScore = -32768;
  int16_t secondScore = -32768;


  for (uint8_t i = 0; i < SENSOR_COUNT; i++)
  {
    if (
      (
        allowedMask &
        (1 << i)
      )
      == 0
    )
    {
      continue;
    }


    int16_t score =
      scorePercent[i];


    if (score > bestScore)
    {
      secondScore =
        bestScore;

      bestScore =
        score;

      bestSensor =
        i;
    }
    else if (score > secondScore)
    {
      secondScore =
        score;
    }
  }


  if (
    bestSensor < 0 ||
    bestScore < TRIGGER_SCORE
  )
  {
    return -1;
  }


  if (
    secondScore >= TRIGGER_SCORE &&
    (
      bestScore -
      secondScore
    )
    < WINNER_MARGIN
  )
  {
    return -1;
  }


  return
    bestSensor;
}


// ============================================================
// NEUTRAL TEST
// ============================================================

bool allowedSensorsNeutral(
  uint8_t allowedMask
)
{
  for (uint8_t i = 0; i < SENSOR_COUNT; i++)
  {
    if (
      (
        allowedMask &
        (1 << i)
      )
      == 0
    )
    {
      continue;
    }


    if (
      scorePercent[i]
      >= RELEASE_SCORE
    )
    {
      return false;
    }
  }


  return true;
}


// ============================================================
// EVENT MACHINE HELPERS
// ============================================================

void resetEventState()
{
  latchedSensor = -1;

  candidateSensor = -1;
  candidateSince = 0;

  releaseSince = 0;
  neutralSince = 0;

  eventArmed = false;
}


#if DEBUG_SERIAL
void printEventScores()
{
  DBG_PRINT(F("SCORES  START="));
  DBG_PRINT(scorePercent[START_ID]);

  DBG_PRINT(F("  UP="));
  DBG_PRINT(scorePercent[UP_ID]);

  DBG_PRINT(F("  DOWN="));
  DBG_PRINT(scorePercent[DOWN_ID]);

  DBG_PRINT(F("  LEFT="));
  DBG_PRINT(scorePercent[LEFT_ID]);

  DBG_PRINT(F("  RIGHT="));
  DBG_PRINTLN(scorePercent[RIGHT_ID]);
}
#endif


// ============================================================
// WAIT FOR ONE COMPLETE PRESS + RELEASE EVENT
//
// Returns:
//   sensor ID on success
//   -1 = press timeout
//   -2 = accepted press did not release before release timeout
//
// IMPORTANT:
// resetEventState() is NOT called here.
// The player turn calls it once before the whole sequence,
// preserving the validated event lifecycle between positions.
// ============================================================

int8_t waitForPressReleaseEvent(
  uint8_t allowedMask,
  unsigned long pressTimeoutMs,
  bool lampFeedback
)
{
  unsigned long pressWaitStarted =
    millis();


  while (true)
  {
    if (
      pressTimeoutMs > 0 &&
      millis() - pressWaitStarted
      >= pressTimeoutMs
    )
    {
      allRelaysOff();

      candidateSensor = -1;
      candidateSince = 0;

      return -1;
    }


    readAllSensors(true);


    // --------------------------------------------------------
    // REARM: require a real neutral interval.
    // --------------------------------------------------------

    if (!eventArmed)
    {
      allRelaysOff();


      if (
        allowedSensorsNeutral(
          allowedMask
        )
      )
      {
        if (neutralSince == 0)
        {
          neutralSince =
            millis();
        }


        if (
          millis() - neutralSince
          >= REARM_NEUTRAL_MS
        )
        {
          eventArmed =
            true;

          candidateSensor = -1;
          candidateSince = 0;

          DBG_PRINTLN(F("ARMED"));
        }
      }
      else
      {
        neutralSince = 0;
      }


      continue;
    }


    // --------------------------------------------------------
    // ARMED: find one stable winner.
    // --------------------------------------------------------

    int8_t winner =
      findValidWinner(
        allowedMask
      );


    if (winner < 0)
    {
      candidateSensor = -1;
      candidateSince = 0;

      continue;
    }


    if (
      candidateSensor
      != winner
    )
    {
      candidateSensor =
        winner;

      candidateSince =
        millis();

      continue;
    }


    if (
      millis() - candidateSince
      < PRESS_STABLE_MS
    )
    {
      continue;
    }


    // --------------------------------------------------------
    // PRESS accepted.
    // --------------------------------------------------------

    latchedSensor =
      winner;

    inputEventCounter++;

    eventArmed = false;

    candidateSensor = -1;
    candidateSince = 0;

    releaseSince = 0;
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
void loop()
{
  runIdle();
}

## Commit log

2026-09-07 Add Glass Memory firmware, 3D print, and laser-cut files with a project gitignore.
    [glass_memory_hand_3Dprint.scad, glass_memory_hand_3Dprint.stl, glass_memory_max7219_beze.scad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]
2026-09-07 Add README, installation photo, and KiCad controller/adapter boards.
    [glass-memory-B_Cu.gbl, glass-memory-B_Mask.gbs, glass-memory-B_Silkscreen.gbo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]
